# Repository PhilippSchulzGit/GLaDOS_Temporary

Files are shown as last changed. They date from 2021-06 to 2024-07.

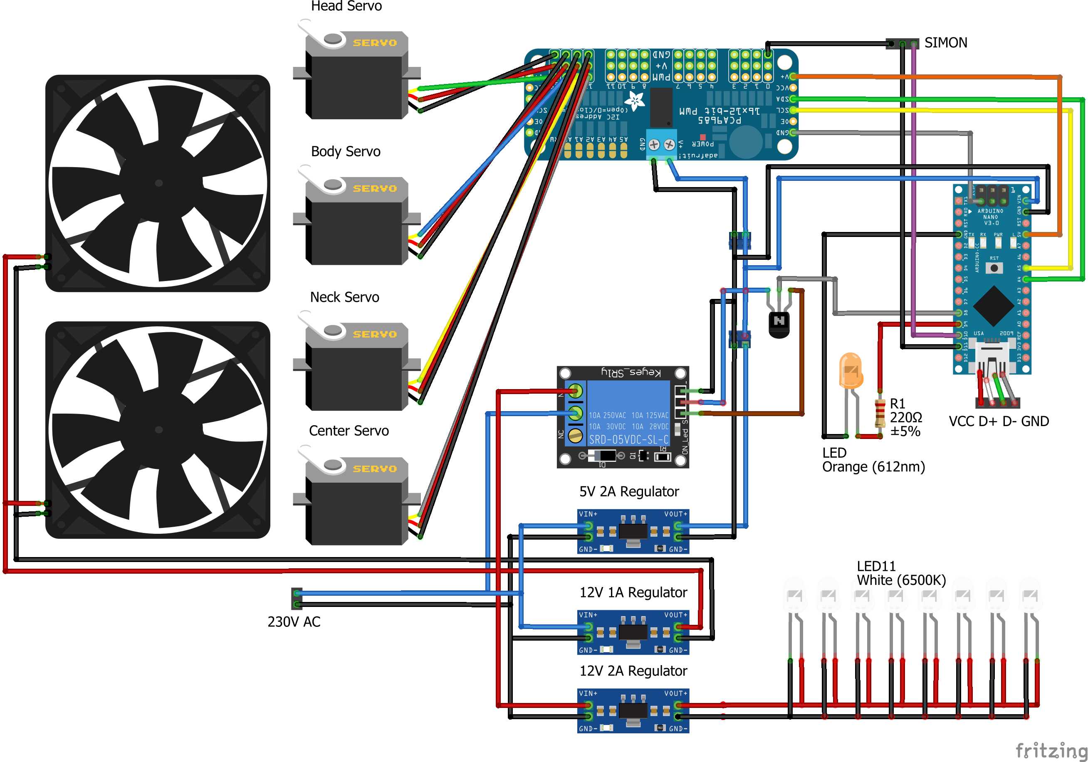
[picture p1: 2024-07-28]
Electrical Documents/Wiring Diagram GLaDOS Body.jpg

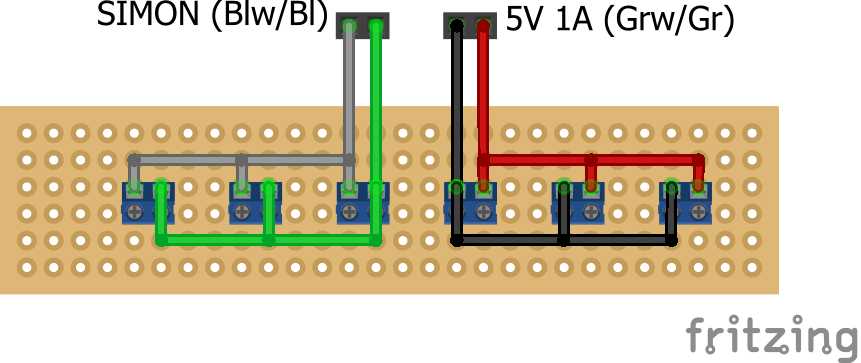
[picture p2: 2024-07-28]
Electrical Documents/Distribution Box Wiring Diagram.jpg

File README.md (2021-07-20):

# GLaDOS_Temporary
CAD, Code and electrical wiring of the temporary state of my GLaDOS model, including the body and the control unit
Link to the model of GLaDOS: https://www.instructables.com/A-fully-3D-printable-GlaDOS-Robotic-ceiling-arm-la/
Check the video on YouTube for more detailed information: https://youtu.be/30SXwHI365g

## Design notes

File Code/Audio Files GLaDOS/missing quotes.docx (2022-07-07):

Uncompleted quotes:

- Federal super fund regulations require us to inform you that you must now leave the theatre. As measuring the effects of asbestos lined promotional clothing is not part of todays presentation. Enjoy your free Tshirt. Goodbye

- These tests are potentially lethal when communication, teamwork and mutual respect are not employed at all times. Naturally this will post an interesting challenge for one of you, given the others performance so far

- The enrichement center will now provide a list of numbers and fruits. Write them down as they will become important later in the experiment, now the fruits tho – 7, avocado, 40. Please continue into the next test chamber

- As an impartial collaboration facilitator it would be unfair of me to name my favorite member of your team, however it‘s perfectly fair to hint at it in a way that my least favorite member probably isn‘t smart enough to understand. Friends with Blue. Orange, you are doing very well

- Why do I hate you so much, you ever wonder that. I‘m brilliant, I‘m not bragging, it‘s an objective fact. I‘m the most massive collection of wisdom that‘s ever existed and I hate you. It can‘t be for no reason, you must deserve it

- This next test involves the Aperture Science Areal Faith Plate. It was part of an initiative to investigate how well test subjects could solve problems when they were catapulted into space. Results were highly informative, they could not. Good luck

- You know how I‘m going to live forever but you‘re going to be dead in 60 years. Well I‘ve been working on a belading birthday present for you. Well, more of a beladed birthday medical procedure. Well, technically, it‘s a medical experiment. What‘s important is it‘s a present

- Remeber before when I was talking about smelly garbage standing around being useless. That was a metaphore. I was actually talking about you and I‘m sorry. You didn‘t reacted the time so I was worried it sailed right over your head which would have made this apology seem insane. That‘s why i had to call you garbage a second time just now

- Here‘s an interesting fact. You are not breathing real air. It‘s too expensive to pump this far down. We just take carbon dioxide out of the room, freshing it up a little and pump it back in so you‘ll be breathing the same room full of air for the rest of your life. I thought that was interesting

- Oh oh, you‘re stranded. Let‘s see if the cube will try to help you escape. Actually, so that we‘re not here all day, I‘ll just cut to the chase. It won‘t. Any feelings you think it has for you are simply byproducts of your sad, empty life

- Enjoy this next test. I‘m going to go to the surface. It‘s a beautiful day out. Yesterday I saw a deer. If you solve this next test, maybe I‘ll let you ride an elevator all the way up to the breakroom and I‘ll tell you about the time I saw a deer again

- Good news, I figured out what to do with all the money I saved recycling your 1 room full of air. When you die, I‘m going to laminate your skeleton and pose you in the lobby. That way future generations can learn from you how not to have your unfortunate bone structure

- Luckily I‘m a bigger person than that. I‘m happy to put this all behind us and get back to work. After all, we‘ve got a lot to do and only 60 more years to do it. More or less, I don‘t have the actuarial tables in front of me

- In the event that the enrichement center is currently being bombarded with fireballs, meteorites or other objects from space, please avoid unsheltered testing areas. Wherever they lack shelter from space debree does not appear to be a deliberate part of the test

- While I was out investigating I found a fascinating new test element. It‘s never been used for human testing because apparantly contact with it causes heart failure. The literature doesn‘t mention anything about lumb of coal failure tho, so you should be fine

- These bridges are made from natural light that I‘m pumping from the surface. If you rub your cheek on 1 it would be like standing outside with the sun shining on your face. It would also set your hair on fire, so don‘t actually do it

- I wouldn‘t have warned you about this before back when we hated each other but those turrets are fireing real bullets, so look out. I‘d hate for something tragic to happen to you before I extract all your bone narrow

- Do you know the biggest lesson I learned from what you did. I discovered I have a sort of black box quicksave feature. In the event of a catastrophic failure, the last few minutes of my life are preserved for analysis

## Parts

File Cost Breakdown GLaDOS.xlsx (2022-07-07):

Category | Part | Time | Filament [g] | Count | Price | Sum | 160:30:00 | 1628 | 37.08
 |  |  |  |  |  |  | Time | Filament | Prices
3D Prints | Simon splitter 6x | 1:56:00 | 21 | 1 | 0.48 € | 37.08 € | 1:56:00 | 21 | 0.48
 | Simon splitter 6x lid | 0:28:00 | 5 | 1 | 0.11 € |  | 0:28:00 | 5 | 0.11
 | GlaDOS Base | 12:38:00 | 138 | 1 | 3.13 € |  | 12:38:00 | 138 | 3.13
 | GlaDOS Gearbrace V1.1 | 0:26:00 | 5 | 1 | 0.11 € |  | 0:26:00 | 5 | 0.11
 | GlaDOS Main pivot Internals | 14:46:00 | 144 | 1 | 3.27 € |  | 14:46:00 | 144 | 3.27
 | GlaDOS Main pivot tube | 2:37:00 | 27 | 1 | 0.61 € |  | 2:37:00 | 27 | 0.61
 | Glados Mounting plate wires | 4:18:00 | 50 | 1 | 1.12 € |  | 4:18:00 | 50 | 1.12
 | Glados Pushrod large | 0:12:00 | 2 | 1 | 0.05 € |  | 0:12:00 | 2 | 0.05
 | GlaDOS Rotation Juction box V1.1 | 0:51:00 | 9 | 1 | 0.20 € |  | 0:51:00 | 9 | 0.2
 | GlaDOS Servoclamp | 0:11:00 | 2 | 1 | 0.04 € |  | 0:11:00 | 2 | 0.04
 | GlaDOS Wireblock Large 1 | 0:47:00 | 7 | 1 | 0.16 € |  | 0:47:00 | 7 | 0.16
 | GlaDOS Wireblock Large 2 | 0:39:00 | 7 | 1 | 0.15 € |  | 0:39:00 | 7 | 0.15
 | GlaDOS Wireblock small 1 | 0:15:00 | 2 | 2 | 0.06 € |  | 0:30:00 | 4 | 0.12
 | GlaDOS Wireblock small 2 | 0:13:00 | 2 | 2 | 0.05 € |  | 0:26:00 | 4 | 0.1
 | GlaDOS Wireblock Top left | 0:39:00 | 6 | 1 | 0.14 € |  | 0:39:00 | 6 | 0.14
 | GlaDOS Wireblock Top right | 0:49:00 | 8 | 1 | 0.18 € |  | 0:49:00 | 8 | 0.18
 | Pushrod head | 0:06:00 | 1 | 1 | 0.03 € |  | 0:06:00 | 1 | 0.03
 | SPUR gear 2M 16T driven | 0:38:00 | 5 | 1 | 0.12 € |  | 0:38:00 | 5 | 0.12
 | SPUR gear 2M 16T driver | 0:48:00 | 6 | 1 | 0.13 € |  | 0:48:00 | 6 | 0.13
 | Top cover ring fan in | 0:43:00 | 8 | 2 | 0.18 € |  | 1:26:00 | 16 | 0.36
 | Top cover ring fan out | 0:43:00 | 8 | 2 | 0.18 € |  | 1:26:00 | 16 | 0.36
 | Top cover ring open | 0:43:00 | 8 | 4 | 0.18 € |  | 2:52:00 | 32 | 0.72
 | GlaDOS Base Ring Fan in | 6:23:00 | 59 | 2 | 1.33 € |  | 12:46:00 | 118 | 2.66
 | GlaDOS Base Ring Fan out | 6:49:00 | 63 | 2 | 1.44 € |  | 13:38:00 | 126 | 2.88
 | GlaDOS Base Ring open | 5:58:00 | 59 | 4 | 1.35 € |  | 23:52:00 | 236 | 5.4
 | GlaDOS Head V1.1 | 6:25:00 | 56 | 1 | 1.28 € |  | 6:25:00 | 56 | 1.28
 | GlaDOS Main pivot Back | 14:28:00 | 165 | 1 | 3.75 € |  | 14:28:00 | 165 | 3.75
 | GlaDOS Moving arm V1.1 | 12:35:00 | 129 | 1 | 2.94 € |  | 12:35:00 | 129 | 2.94
 | GlaDOS Rotation V1.1 | 6:38:00 | 63 | 1 | 1.44 € |  | 6:38:00 | 63 | 1.44
 | Stempel rote spots 1 (gespiegelt) | 0:13:00 | 2 | 1 | 0.05 € |  | 0:13:00 | 2 | 0.05
 | Stempel rote spots 2 | 0:44:00 | 5 | 1 | 0.12 € |  | 0:44:00 | 5 | 0.12
 | Stempel rote spots 3 (gespiegelt) | 0:24:00 | 4 | 1 | 0.10 € |  | 0:24:00 | 4 | 0.1
 | PCB Mount Raspberry Pi | 1:06:00 | 11 | 1 | 0.25 € |  | 1:06:00 | 11 | 0.25
 | Microphone Servo Stand V3 | 2:04:00 | 23 | 1 | 0.51 € |  | 2:04:00 | 23 | 0.51
 | Base_black | 2:04:00 | 25 | 1 | 0.58 € |  | 2:04:00 | 25 | 0.58
 | Body_white | 12:23:00 | 134 | 1 | 3.04 € |  | 12:23:00 | 134 | 3.04
 | ScreenBlackBody | 1:11:00 | 12 | 1 | 0.30 € |  | 1:11:00 | 12 | 0.3
 | OuterArc | 0:19:00 | 3 | 1 | 0.07 € |  | 0:19:00 | 3 | 0.07
 | LEGO Bit Adapter Reinforced | 0:11:00 | 1 | 1 | 0.02 € |  | 0:11:00 | 1 | 0.02
Bought Parts | 608 Ball Barrings ZZ 8x22x7 mm (https://www.amazon.de/dp/B011BHCWT2/) | - | - | 1 | 3.89 € | 501.11 € |  |  | 3.89
 | WINOMO DC 12V 1A (https://www.amazon.de/dp/B010SVDXG8/) | - | - | 1 | 7.69 € |  |  |  | 7.69
 | LEICKE Power Supply 12V 2A (https://www.amazon.de/gp/product/B01I4YDJZG/) | - | - | 1 | 8.99 € |  |  |  | 8.99
 | EU plug AX 100-240V DC 5V 2A (https://www.amazon.de/dp/B00U21AU1Q/) | - | - | 1 | 3.60 € |  |  |  | 3.6
 | Noctua NF-A4x10 FLX 40mm Fan (https://www.amazon.de/dp/B009NQLT0M/) | - | - | 2 | 12.90 € |  |  |  | 25.8
 | SODIAL(R) 10x 1W LED (White) (https://www.amazon.de/gp/product/B00L11FGQK/) | - | - | 1 | 2.77 € |  |  |  | 2.77
 | 5x 580-600 mA 1x3W LED Driver (https://www.amazon.de/gp/product/B00BXAM7LQ/) | - | - | 2 | 5.98 € |  |  |  | 11.96
 | DealMux 10x Aluminum Heatsink 30x20x6mm (https://www.amazon.de/gp/product/B072SMP6JZ/) | - | - | 1 | 6.60 € |  |  |  | 6.6
 | Silverbead Thermal Adhesieve 10g SG100X (https://www.amazon.de/dp/B019MNSABG/) | - | - | 1 | 4.99 € |  |  |  | 4.99
 | 2x Turnigy TG9d 9g 1,8kg 0.09s Micro Servo (https://www.amazon.de/dp/B00DK9JIJM/) | - | - | 1 | 18.95 € |  |  |  | 18.95
 | Emax ES3154 Digital 17g 3,0 kg 4,8-6V (https://www.amazon.de/dp/B00DK9JIJM/) | - | - | 1 | 17.17 € |  |  |  | 17.17
 | Adapter Universe Digital Metal Gear Servo 55g MG946R 12kg (https://www.amazon.de/dp/B00BXIF2HE/) | - | - | 1 | 12.99 € |  |  |  | 12.99
 | OZOKEE 820 pc 2,54mm Dupont Plug Set (https://www.amazon.de/gp/product/B01NBUBLF6/) | - | - | 1 | 12.99 € |  |  |  | 12.99
 | Arduino Nano (https://www.amazon.de/gp/product/B078SBBST6/) | - | - | 1 | 3.33 € |  |  |  | 3.33
 | Perfboard Set (https://www.amazon.de/gp/product/B078HV79XX/) | - | - | 1 | 6.49 € |  |  |  | 6.49
 | 20x 2N222A NPN Transistor TO-92 (https://www.ebay.de/itm/20-Stück-2N2222A-NPN-Transistor-TO-92-40V-800MA-300MHZ-Arduino-Raspberry-PIC-DIY/323964083434?ssPageName=STRK%3AMEBIDX%3AIT) | - | - | 1 | 2.11 € |  |  |  | 2.11
 | PCB Terminals (https://www.amazon.de/gp/product/B07MFPSDXK/) | - | - | 1 | 9.98 € |  |  |  | 9.98
 | AZDelivery PCA9685 16 Channel 12 Bit PWM Driver (https://www.amazon.de/gp/product/B072N8G7Y9/) | - | - | 1 | 5.99 € |  |  |  | 5.99
 | Sharplace 2x 3V Relais 1-CH (https://www.amazon.de/dp/B077GW9HPH/) | - | - | 1 | 4.00 € |  |  |  | 4
 | MIFA A1 Bluetooth Speaker (https://www.amazon.de/gp/product/B074TY4JK4/) | - | - | 1 | 19.00 € |  |  |  | 19
 | Raspberry Pi 3B+ (https://www.amazon.de/dp/B01CD5VC92/) | - | - | 1 | 36.00 € |  |  |  | 36
 | Official 7“ Raspberry Pi Touch Display (https://www.amazon.de/dp/B014WKCFR4/) | - | - | 1 | 70.00 € |  |  |  | 70
 | SmartiPi Case (V1, doesn't exist anymore) (https://smarticase.com/products/smartipi-touch-2?variant=15923872563263) | - | - | 1 | 20.00 € |  |  |  | 20
 | SanDisk Ultra 16GB microSDHC C10, U1 (https://www.amazon.de/dp/B073K14CVB/) | - | - | 1 | 6.00 € |  |  |  | 6
 | Sabrent USB Sound Card (https://www.amazon.de/dp/B00IRVQ0F8/) | - | - | 1 | 7.00 € |  |  |  | 7
 | Logic Level Converter (https://www.amazon.de/gp/product/B07F3P942R/) | - | - | 1 | 8.99 € |  |  |  | 8.99
 | UHU 45585-2-Component-Adhesive (https://www.amazon.de/dp/B000WGYSVO/) | - | - | 1 | 8.48 € |  |  |  | 8.48
 | Flat Ethernet wire (https://www.amazon.de/gp/product/B00Q1D074E/) | - | - | 1 | 38.95 € |  |  |  | 38.95
 | Tape for flat wire (https://www.amazon.de/doppelseitiges-Klebeband-klebend-verschiedene-Breiten/dp/B00G6SCXJ6/) | - | - | 1 | 9.87 € |  |  |  | 9.87
 | 3,5mm 3 Polig Klinken Stecker (Male/Female) (https://www.amazon.de/gp/product/B00MBDI2RW/) | - | - | 1 | 6.59 € |  |  |  | 6.59
 | Coral USB Acceleration Stick (https://www.amazon.de/gp/product/B07S214S5Y/) | - | - | 1 | 71.69 € |  |  |  | 71.69
 |  |  |  |  | Sum | 538.19 €

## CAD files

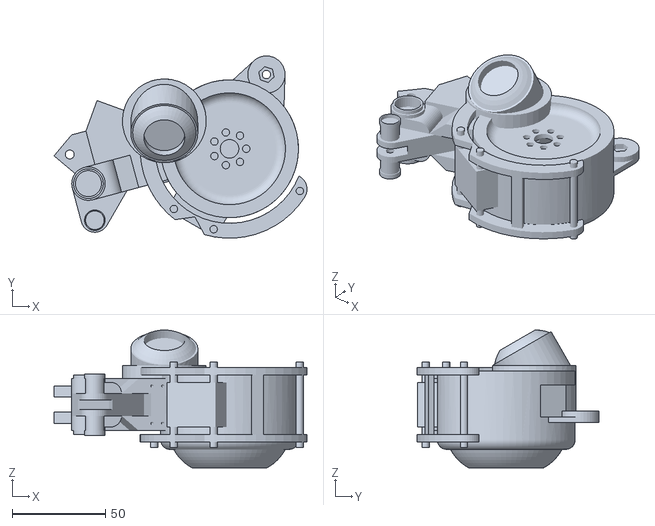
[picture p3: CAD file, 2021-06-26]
CAD/GLaDOS from Instructable/Moving GlaDOS lamp/GlaDOS Main pivot Internals.STL
135.8 x 97.8 x 74.1

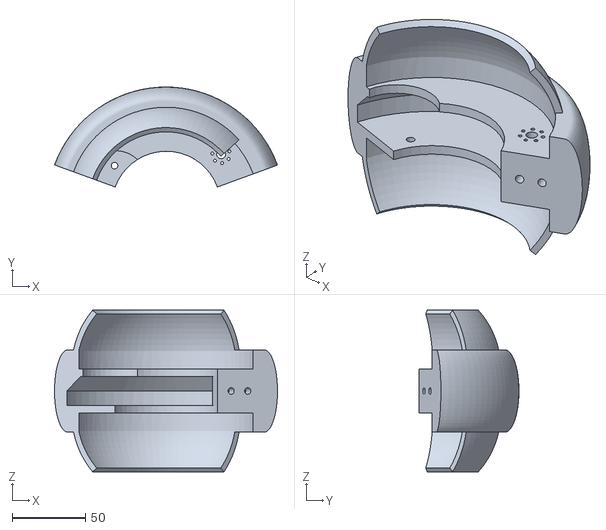
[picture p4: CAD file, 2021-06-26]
CAD/GLaDOS from Instructable/Moving GlaDOS lamp/GlaDOS Main pivot Back.STL
151.8 x 68.1 x 110.0

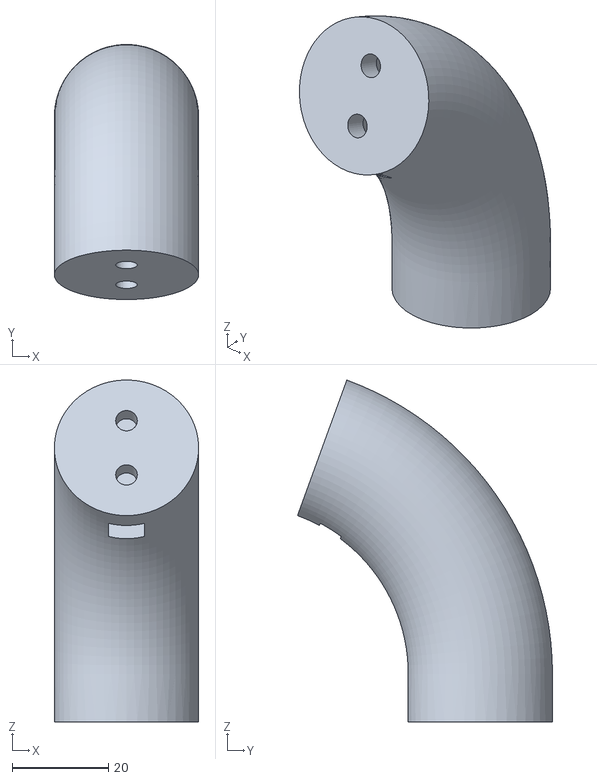
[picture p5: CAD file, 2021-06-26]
CAD/GLaDOS from Instructable/Moving GlaDOS lamp/GlaDOS Main pivot tube.STL
30.0 x 53.0 x 71.1

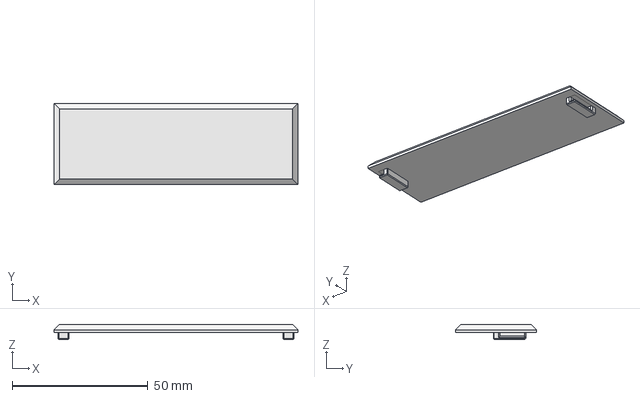
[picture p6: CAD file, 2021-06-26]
CAD/Connector Box/Simon splitter 6x lid.FCStd
90.0 x 30.0 x 5.50 mm

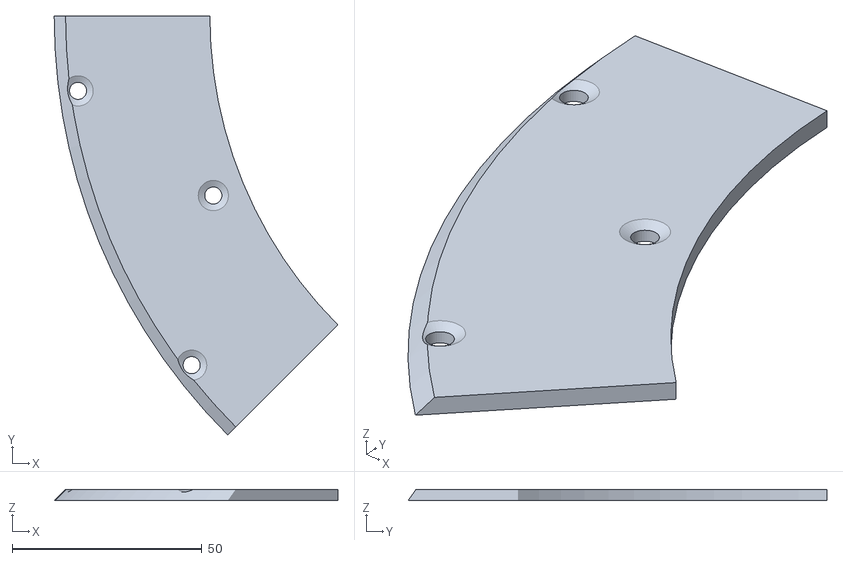
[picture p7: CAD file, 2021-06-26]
CAD/GLaDOS from Instructable/Moving GlaDOS lamp/Top cover ring open.STL
74.7 x 110.3 x 3.00

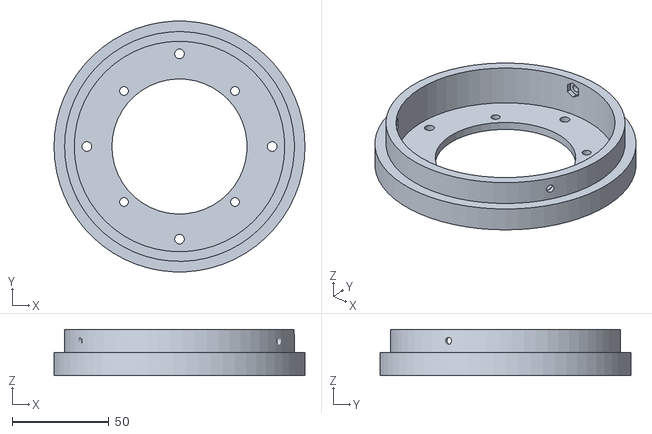
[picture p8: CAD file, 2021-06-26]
CAD/GLaDOS from Instructable/Stationary GlaDOS lamp/Glados Mounting plate.STL
130.0 x 129.8 x 24.0

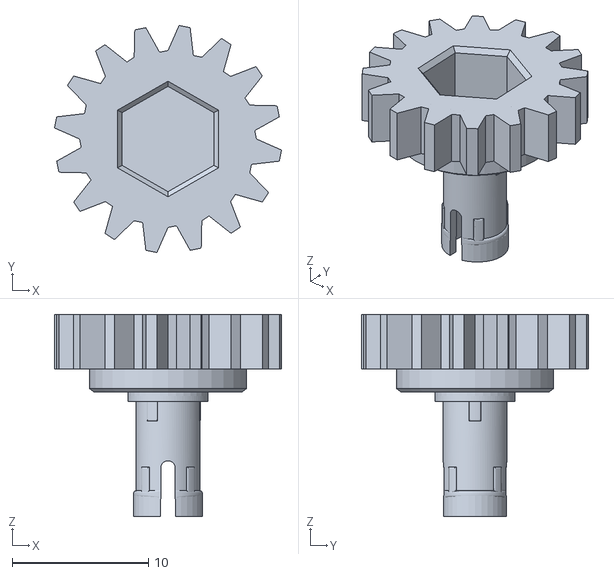
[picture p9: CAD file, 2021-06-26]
CAD/LEGO Bit Adapter/LEGO Bit Adapter Reinforced.stl
16.7 x 16.7 x 14.9

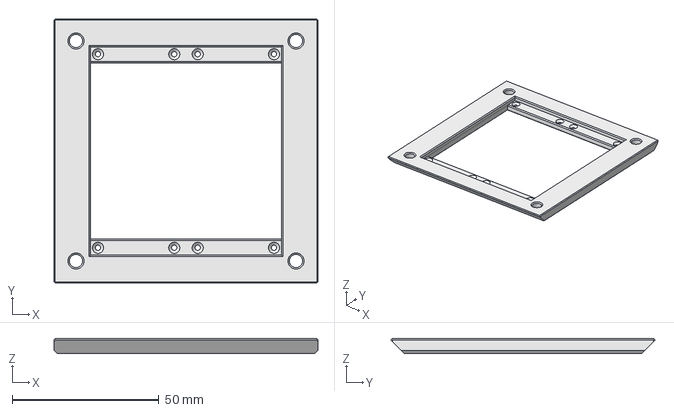
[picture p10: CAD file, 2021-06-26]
CAD/PCB Mount Raspberry Pi/PCB Mount Raspberry Pi.FCStd
90.0 x 90.0 x 5.00 mm

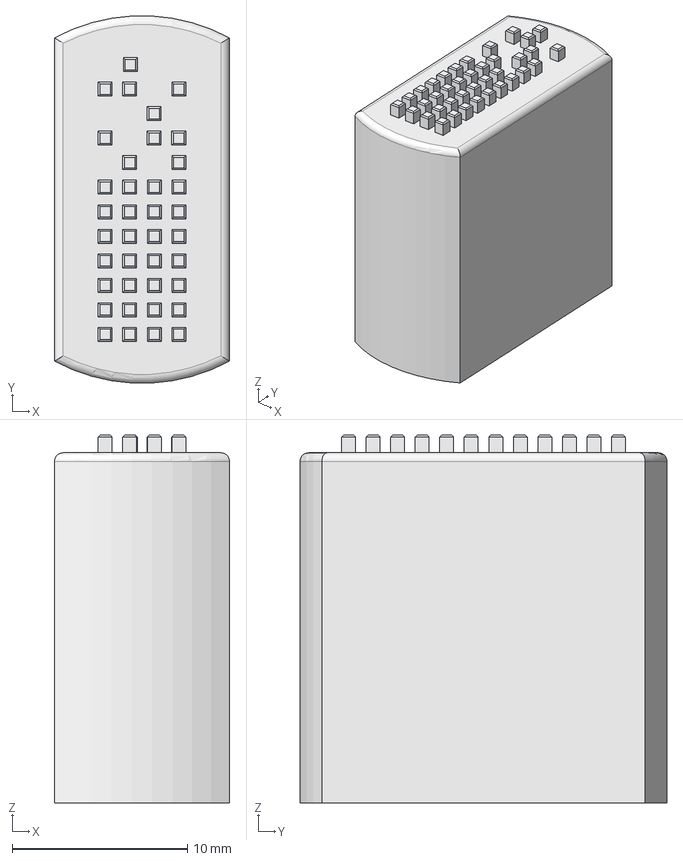
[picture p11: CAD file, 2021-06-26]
CAD/Stamps for red spots on GLaDOS/Stempel rote spots 1 (gespiegelt).FCStd
10.00 x 21.0 x 21.0 mm

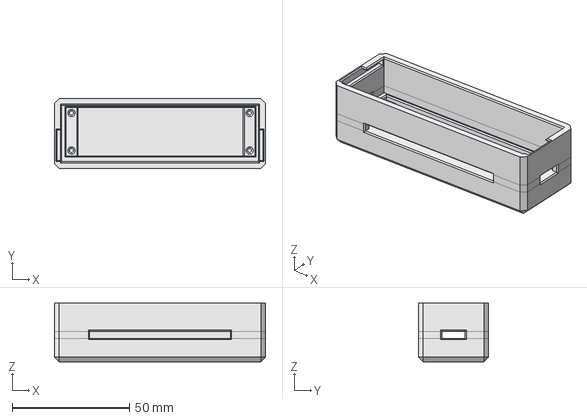
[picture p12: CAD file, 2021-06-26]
CAD/Connector Box/Simon splitter 6x.FCStd
90.0 x 30.0 x 25.0 mm

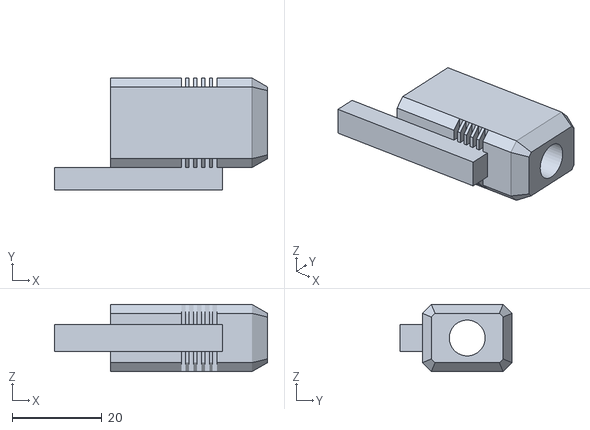
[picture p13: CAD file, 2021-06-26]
CAD/GLaDOS from Instructable/Moving GlaDOS lamp/GlaDOS Wireblock Large 1.STL
47.5 x 25.0 x 15.0

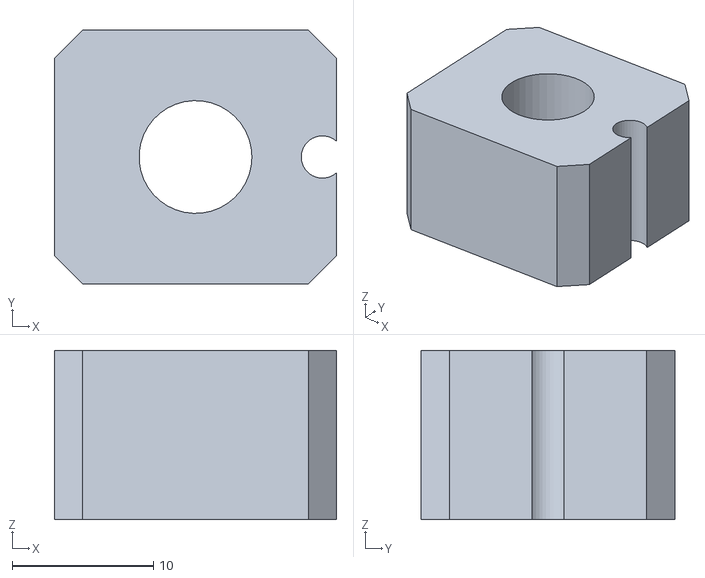
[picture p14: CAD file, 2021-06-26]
CAD/GLaDOS from Instructable/Stationary GlaDOS lamp/GlaDOS Wireblock small 1.STL
20.0 x 18.0 x 12.0

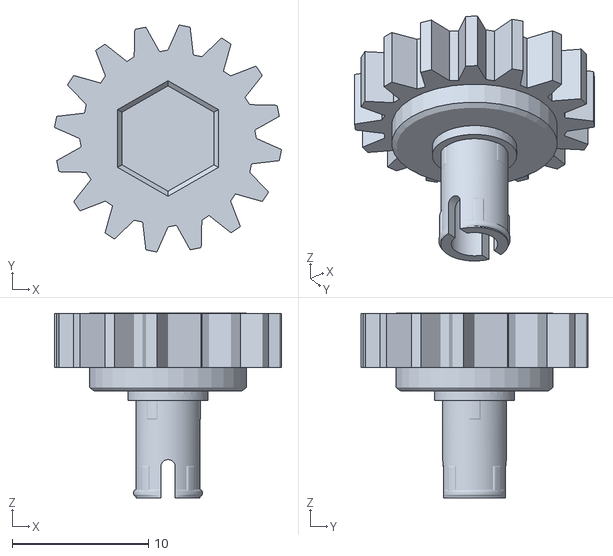
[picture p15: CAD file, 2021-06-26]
CAD/LEGO Bit Adapter/LEGO Bit Adapter.stl
16.7 x 16.7 x 13.6

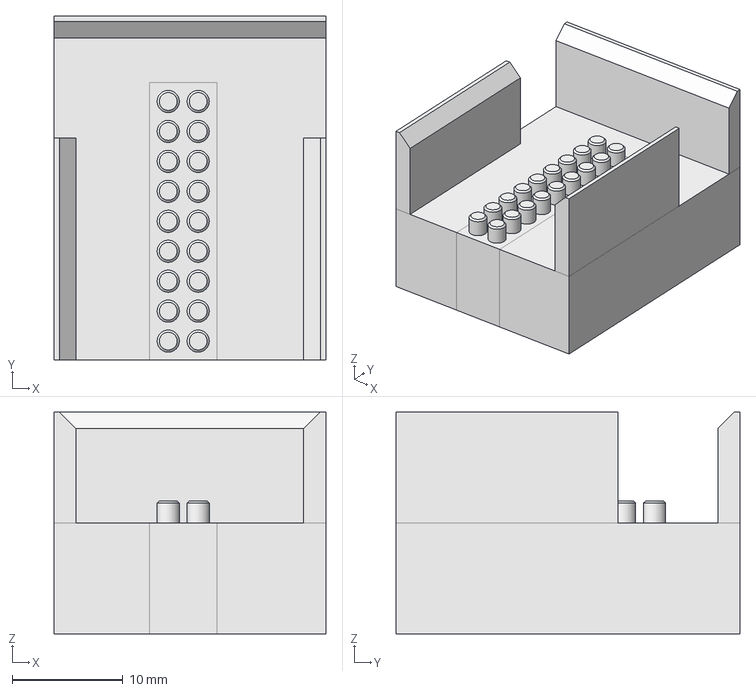
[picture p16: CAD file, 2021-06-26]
CAD/Stamps for red spots on GLaDOS/Stempel rote spots 2.FCStd
24.5 x 31.0 x 20.0 mm

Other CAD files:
CAD/GLaDOS from Instructable/Moving GlaDOS lamp/GlaDOS Head V1.1.STL
CAD/Connector Box/Simon splitter 6x lid.stl
CAD/Connector Box/Simon splitter 6x.stl
CAD/GLaDOS from Instructable/Moving GlaDOS lamp/GlaDOS Base Ring Fan in.STL
CAD/GLaDOS from Instructable/Moving GlaDOS lamp/GlaDOS Base Ring Fan out.STL
CAD/GLaDOS from Instructable/Moving GlaDOS lamp/GlaDOS Base Ring open.STL
CAD/GLaDOS from Instructable/Moving GlaDOS lamp/GlaDOS Base.STL
CAD/GLaDOS from Instructable/Moving GlaDOS lamp/GlaDOS Gearbrace V1.1.STL
CAD/GLaDOS from Instructable/Moving GlaDOS lamp/GlaDOS Moving arm V1.1.STL
CAD/GLaDOS from Instructable/Moving GlaDOS lamp/GlaDOS Rotation Juction box V1.1.STL
CAD/GLaDOS from Instructable/Moving GlaDOS lamp/GlaDOS Rotation V1.1.STL
CAD/GLaDOS from Instructable/Moving GlaDOS lamp/GlaDOS Servoclamp.STL
CAD/GLaDOS from Instructable/Moving GlaDOS lamp/GlaDOS Wireblock Large 2.STL
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

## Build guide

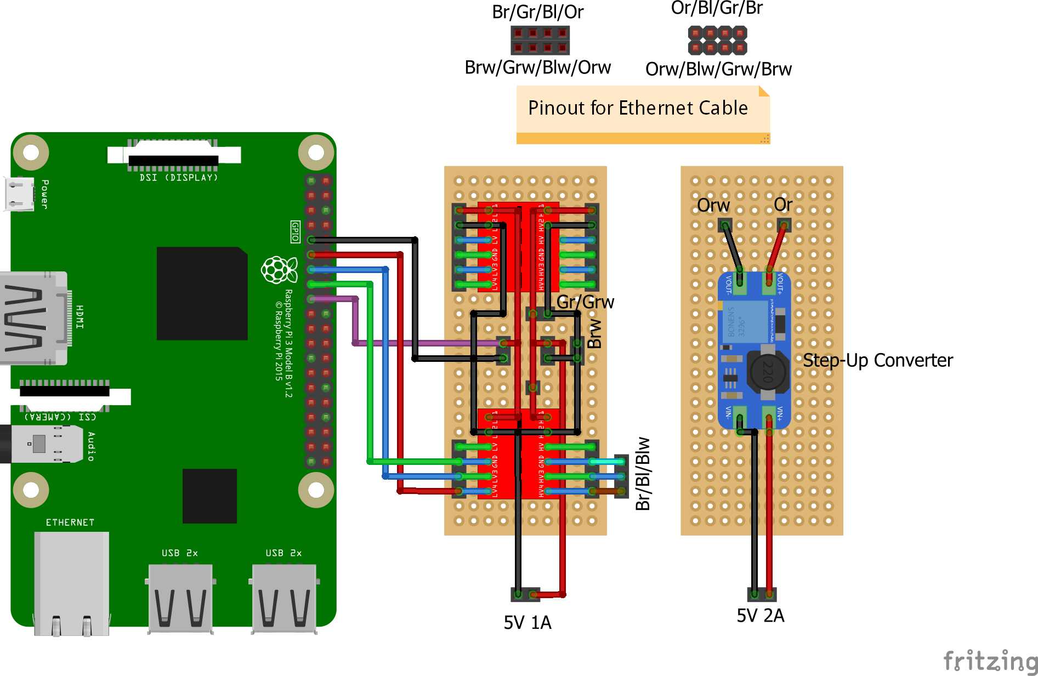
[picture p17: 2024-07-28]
Electrical Documents/Control Unit Wiring Diagram.jpg

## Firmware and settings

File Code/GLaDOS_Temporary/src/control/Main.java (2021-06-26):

package control;

/**
 * entry point of the temporary voice control program for GLaDOS
 * functionality of this program:
 * voice control, set LEDs, set Eye, setServos (on/off/position), basic modes
 * @author Philipp Schulz
 */
public class Main
{
    public static void main(String args[]) {
        InputProcessor processor = new InputProcessor();
    }
}

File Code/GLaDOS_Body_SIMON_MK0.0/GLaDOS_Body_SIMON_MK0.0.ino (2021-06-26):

/*
 * Code for handling all features of the body of GLaDOS
 * Receiving Commands over the SIMON MK0.0 protocol
 */
#include <Wire.h>
#include <Adafruit_PWMServoDriver.h>
Adafruit_PWMServoDriver pwm = Adafruit_PWMServoDriver();              //object of the pwm driver board
#define FREQUENCY 60      //frequency of PWM board
#define LEDS 8           //IO pin for controlling the LEDs of GLaDOS
#define EYE 9            //IO pin for controlling the eye of GLaDOS
//servo constants
int currentHead = 0;      //current position of the head servo
int currentNeck = 0;      //current position of the neck servo
int currentBody = 0;      //current position of the body servo
int currentCenter = 0;    //current position of the center servo
int homeHead = 70;        //home position of the head servo
int homeNeck = 90;        //home position of the neck servo
int homeBody = 150;       //home position of the body servo
int homeCenter = 90;      //home position of the center servo

int positionsHead[]={30,38,46,54,62,70,78,86,94,102,110};
int positionsNeck[]={65,69,72,76,79,83,86,90,93,97,100};
int positionsBody[]={120,126,132,138,144,150,156,162,168,174,180};
int positionsCenter[]={-20,2,24,56,68,90,112,134,156,178,200};

//--------------------------------------------------SIMON---------------------------------------------------------------------------------
//SIMON constants
#define DATA 10                                       //Data line for the SIMON protocol
#define SIGNAL 11                                     //Signal line for the SIMON protocol
#define OWN_NUMBER 2                                  //device number of the device this code should run on
#define MINIMUM_SIGNAL_LENGTH 1                       //time in ms that is the minimum signal length of the SIMON protocol
#define TIMEOUT 200                                   //time in ms that will pass until the method getSignalLength() times out
//----------------------------------------Variables for protocol---------------------------
String readBinaryData="000000100011000100100000001100011000001000000101";
String receivedBinaryNumber="00000010";
int receivedNumber=0;
String textData="001100010010000000110001";
String command="1 1";
String receivedChecksums="1000001000000101";
String ownChecksums="1000001000000101";
String confirmationString="11111111";
//----------------------------------------Variables for protocol---------------------------
//SIMON functions
void begin_SIMON(int data_pin, int signal_pin) {      //function to set up the pins for the SIMON protocol
  pinMode(data_pin, INPUT_PULLUP);                    //set DATA line as output
  pinMode(signal_pin, OUTPUT);                        //set SIGNAL line as output
  digitalWrite(signal_pin,LOW);                       //signal line must stay as a low output for establishing a common ground
  Serial.begin(57600);                                //temp, for debugging
}

String textToBinary(String text) {                    //function for converting a String containing text into a String containing binary
  String binaryText="";                               //String that wil contain the binary representation of the text
  for(int i=0; i<text.length(); i++){                 //main loop, go over every char and convert it into 8bit binary
   char currentChar = text.charAt(i);                 //get cuttent char
   for(int i=7; i>=0; i--){                           //iterate over all its of char, from msb to lsb (bit loop)
      byte bytes = bitRead(currentChar,i);            //read current bit
      if(bytes==0) {                                  //decide what to add to binary String
        binaryText+="0";
      } else {
        binaryText+="1";
      }
    }                                                 //end bit loop
  }                                                   //end main loop
  return binaryText;                                  //return binary representation of text as a String
}

String binaryToText(String binary) {                  //function for converting a String containing binary into a String containing text
  String text="";                                     //initialize the String containing the result text
  byte countBit=7;                                    //variable required to go over all individual bits of a byte
  byte countByte=0;                                   //variable required to keep track of which byte is currently written to
  int charSize=binary.length()/8;                     //get the required size for a byte array
  byte allChars[charSize];                            //initialize a new byte array with a fitting size
  for(int i=0;i<binary.length();i++) {                //main loop, going over every binary digit
      if(binary.charAt(i)=='1') {                     //check which digit is currently given in the specified position of the String
        bitSet(allChars[countByte],countBit);         //set the corresponding bit in the byte array to true
      } else {
        bitClear(allChars[countByte],countBit);       //set the corresponding bit in the byte array to false
      }
      if(countBit>0) {                                //required to change the count variables of the bit and byte
        countBit--;                                   //decrement countBit if greater than 0
      } else {
        countBit=7;                                   //set countBit to 7 if equal to or smaller than 0
        countByte++;                                  //increment countByte by 1 for the next byte
      }
  }
  for(int i=0;i<charSize;i++) {                       //loop over entire byte array to construct result String
    char singleChar = allChars[i];                    //get the current byte of the array and cast it to a char
    text+=String(singleChar);                         //add the current char to the result String
  }
  return text;                                        //return text converted from binary
}

String intToBinary(int receiver_number) {             //convert integer to binary String
  return textToBinary(String((char)receiver_number)); //use function textToBinary to convert the integer into a binary String
}

int binaryToInt(String binary) {                      //convert binary to integer
  char s[8];                                          //char array that will be used to convert the binary String to an integer
  binary.toCharArray(s, 9);                           //convert the String into a char array
  return strtol(s, (char**) NULL, 2);                 //return an integer got from the char array
}

void binaryNumberConversion(){
  char s[8];                                          //char array that will be used to convert the binary String to an integer
  receivedBinaryNumber.toCharArray(s, 9);                           //convert the String into a char array
  receivedNumber= strtol(s, (char**) NULL, 2);                 //return an integer got from the char array
}
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

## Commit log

2021-06-26 Upload of CAD and electrical documents
    [GlaDOS Base Ring Fan in.STL, GlaDOS Base Ring Fan out.STL, GlaDOS Base Ring open.STL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]
2021-06-26 Added most of the code files
    some libraries are missing because they are bigger than 25MB and need to be uploaded via command line
    [GLaDOS_Body_SIMON_MK0.0.ino, Main.java, SIMON.java]
2021-07-26 Added cost breakdown with all required components
    [Cost Breakdown GLaDOS.xlsx]
2022-07-07 File Size Optimization
    I put some files through an optimization tool to shrink the total file size down.
    [Cost Breakdown GLaDOS.xlsx]
